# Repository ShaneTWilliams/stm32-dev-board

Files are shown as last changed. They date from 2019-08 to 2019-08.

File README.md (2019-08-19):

# stm32-dev-board
### ***A small-footprint, custom development PCB for the STM32 platform***

* This board's MCU is an STM32F072CBT6, meaning it is a higher-end 48-pin LQFP chip with 128kB of flash and an ARM Cortex-M0 core.

* The board supports CANbus, LINbus, I<sup>2</sup>C, SPI, USB,  and UART. Flashing can be achieved through an ST-LINK external flasher using the SWD protocol.

* The board is powered through a Micro-USB port and draws very little current. Power conversion occurs through a 5~3.3V linear regulator.

* The board has a 32.768kHz clock for RTC capabilities as well as an 8MHz system clock. It also features an indicator LED and a reset button.

* The footprint of the board is 19x52 mm and its 2.54 mm pitch headers allow it to be used with standard breadboards.

### Images ###






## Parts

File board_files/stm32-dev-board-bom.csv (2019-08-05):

Id | Designator | Package | Quantity | Designation | Supplier and ref
1 | C1,C4,C10 | C_0805_2012Metric_Pad1.15x1.40mm_HandSolder | 3 | 1u
2 | C2,C3,C8,C9 | C_0805_2012Metric_Pad1.15x1.40mm_HandSolder | 4 | 15p
3 | C5 | C_0805_2012Metric_Pad1.15x1.40mm_HandSolder | 1 | 10n
4 | C6,C7 | C_0805_2012Metric_Pad1.15x1.40mm_HandSolder | 2 | 4.7u
5 | C11,C12,C13,C14 | C_0805_2012Metric_Pad1.15x1.40mm_HandSolder | 4 | 100n
6 | D1 | LED_0805_2012Metric_Pad1.15x1.40mm_HandSolder | 1 | LED
7 | J1 | USB_Micro-B_Amphenol_10103594-0001LF_Horizontal | 1 | USB_B_Micro
8 | J2,J3 | PinHeader_1x20_P2.54mm_Vertical | 2 | Conn_01x20
9 | R1,R3,R4,R5,R6,R7 | R_0805_2012Metric_Pad1.15x1.40mm_HandSolder | 6 | 0
10 | R2 | R_0805_2012Metric_Pad1.15x1.40mm_HandSolder | 1 | 1k
11 | SW1 | PTS645SM43SMTR92_Switch | 1 | SW_Push
12 | U1 | SOT-223 | 1 | TC1262-33
13 | U2 | LQFP-48_7x7mm_P0.5mm | 1 | STM32F072CBT6
14 | Y1 | 2-SMD_Crystal | 1 | 8M
15 | Y2 | FC-135 | 1 | 32.768k

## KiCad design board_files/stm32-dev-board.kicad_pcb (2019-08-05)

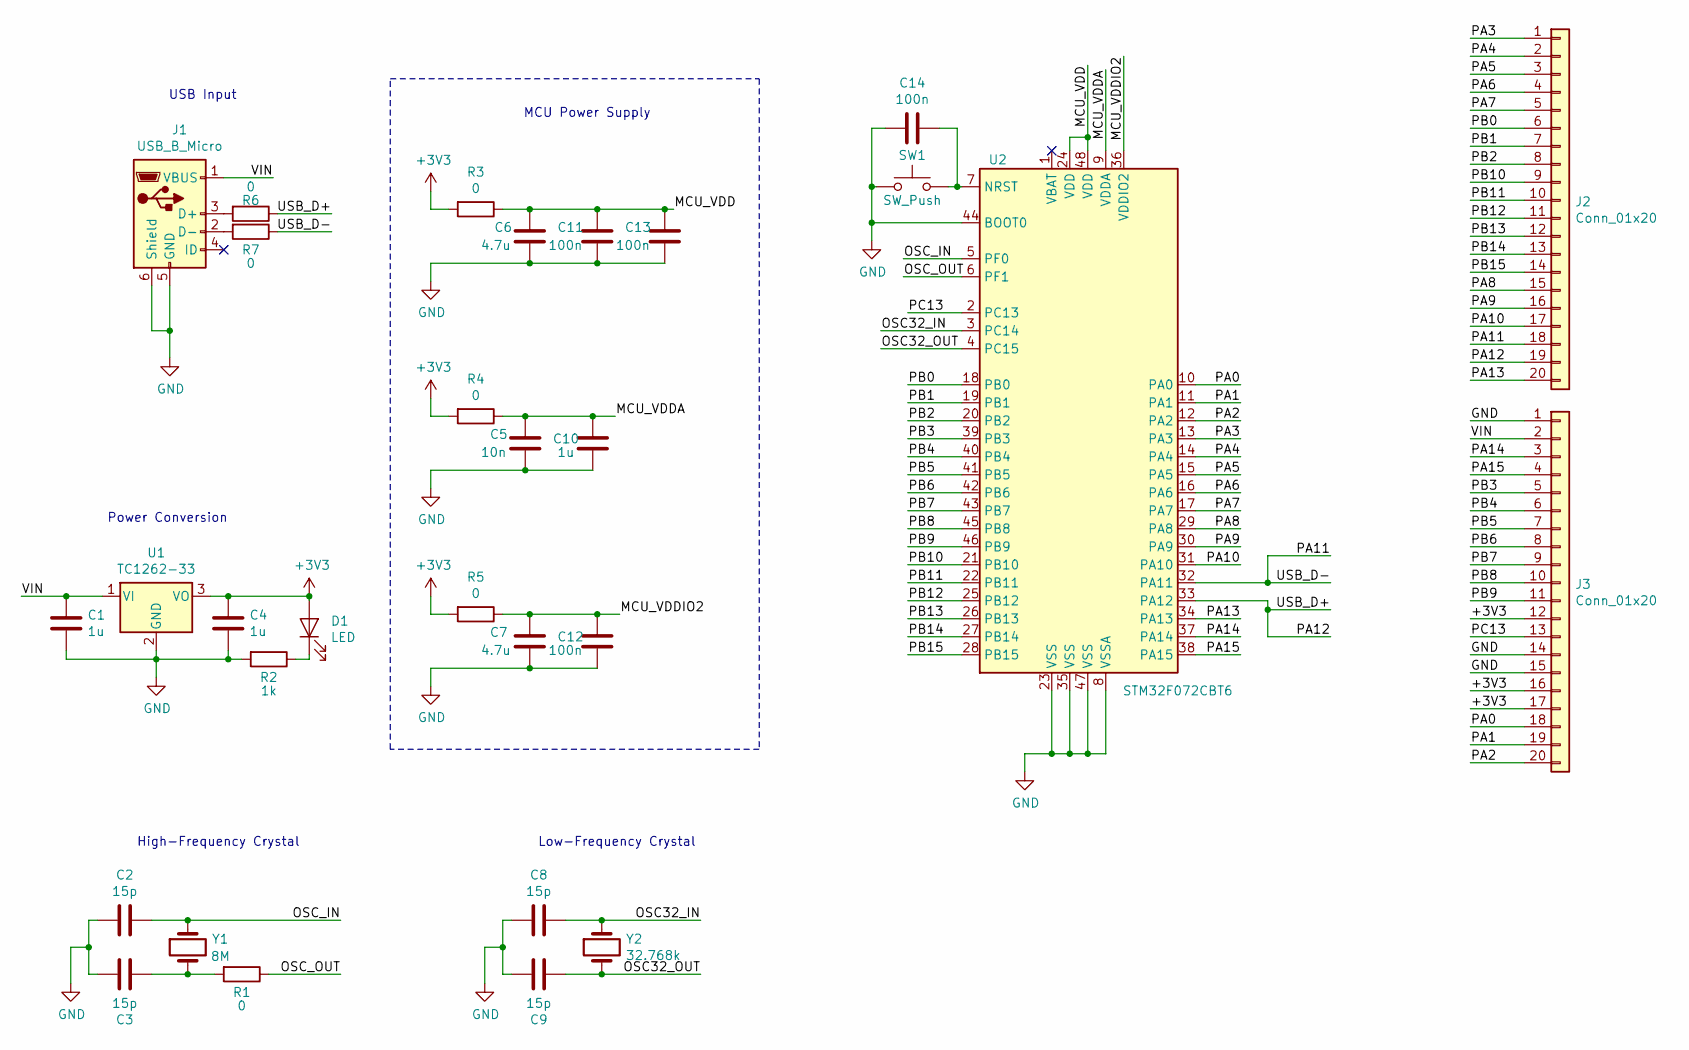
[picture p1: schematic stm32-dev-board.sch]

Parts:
C1, C4, C10: 1u; C_0805_2012Metric_Pad1.15x1.40mm_HandSolder
C2, C3, C8, C9: 15p; C_0805_2012Metric_Pad1.15x1.40mm_HandSolder
C5: 10n; C_0805_2012Metric_Pad1.15x1.40mm_HandSolder
C6, C7: 4.7u; C_0805_2012Metric_Pad1.15x1.40mm_HandSolder
C11, C12, C13, C14: 100n; C_0805_2012Metric_Pad1.15x1.40mm_HandSolder
D1: LED; LED_0805_2012Metric_Pad1.15x1.40mm_HandSolder
J1: USB_B_Micro; USB_Micro-B_Amphenol_10103594-0001LF_Horizontal
J2, J3: Conn_01x20; PinHeader_1x20_P2.54mm_Vertical
R1, R3, R4, R5, R6, R7: 0; R_0805_2012Metric_Pad1.15x1.40mm_HandSolder
R2: 1k; R_0805_2012Metric_Pad1.15x1.40mm_HandSolder
SW1: SW_Push; PTS645SM43SMTR92_Switch
U1: TC1262-33; SOT-223
U2: STM32F072CBT6; LQFP-48_7x7mm_P0.5mm
Y1: 8M; 2-SMD_Crystal
Y2: 32.768k; FC-135

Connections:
+3V3: C4.2, D1.2 (A), J3.12, J3.16, J3.17, R3.2, R4.2, R5.2, U1.3 (VO)
/MCU_VDD: C6.1, C11.1, C13.1, R3.1, U2.24 (VDD), U2.48 (VDD)
/MCU_VDDA: C5.1, C10.1, R4.1, U2.9 (VDDA)
/MCU_VDDIO2: C7.1, C12.1, R5.1, U2.36 (VDDIO2)
/OSC32_IN: C8.1, U2.3 (PC14), Y2.1
/OSC32_OUT: C9.2, U2.4 (PC15), Y2.2
/OSC_IN: C2.1, U2.5 (PF0), Y1.1
/OSC_OUT: R1.1, U2.6 (PF1)
/PA0: J3.18, U2.10 (PA0)
/PA1: J3.19, U2.11 (PA1)
/PA2: J3.20, U2.12 (PA2)
/PA3: J2.1, U2.13 (PA3)
/PA4: J2.2, U2.14 (PA4)
/PA5: J2.3, U2.15 (PA5)
/PA6: J2.4, U2.16 (PA6)
/PA7: J2.5, U2.17 (PA7)
/PA8: J2.15, U2.29 (PA8)
/PA9: J2.16, U2.30 (PA9)
/PA10: J2.17, U2.31 (PA10)
/PA11: J2.18, R7.1, U2.32 (PA11)
/PA12: J2.19, R6.1, U2.33 (PA12)
/PA13: J2.20, U2.34 (PA13)
/PA14: J3.3, U2.37 (PA14)
/PA15: J3.4, U2.38 (PA15)
/PB0: J2.6, U2.18 (PB0)
/PB1: J2.7, U2.19 (PB1)
/PB2: J2.8, U2.20 (PB2)
/PB3: J3.5, U2.39 (PB3)
/PB4: J3.6, U2.40 (PB4)
/PB5: J3.7, U2.41 (PB5)
/PB6: J3.8, U2.42 (PB6)
/PB7: J3.9, U2.43 (PB7)
/PB8: J3.10, U2.45 (PB8)
/PB9: J3.11, U2.46 (PB9)
/PB10: J2.9, U2.21 (PB10)
/PB11: J2.10, U2.22 (PB11)
/PB12: J2.11, U2.25 (PB12)
/PB13: J2.12, U2.26 (PB13)
/PB14: J2.13, U2.27 (PB14)
/PB15: J2.14, U2.28 (PB15)
/PC13: J3.13, U2.2 (PC13)
/VIN: C1.2, J1.1 (VBUS), J3.2, U1.1 (VI)
GND: C1.1, C2.2, C3.1, C4.1, C5.2, C6.2, C7.2, C8.2, C9.1, C10.2, C11.2, C12.2, C13.2, C14.2, J1.5 (GND), J1.6 (Shield), J3.1, J3.14, J3.15, R2.2, SW1.1, U1.2 (GND), U1.4, U2.8 (VSSA), U2.23 (VSS), U2.35 (VSS), U2.44 (BOOT0), U2.47 (VSS)
unnamed: C3.2, R1.2, Y1.2
unnamed: C14.1, SW1.2, U2.7 (NRST)
unnamed: D1.1 (K), R2.1
unnamed: J1.2 (D-), R7.2
unnamed: J1.3 (D+), R6.2

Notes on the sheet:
High-Frequency Crystal
Low-Frequency Crystal
USB Input
Power Conversion
MCU Power Supply

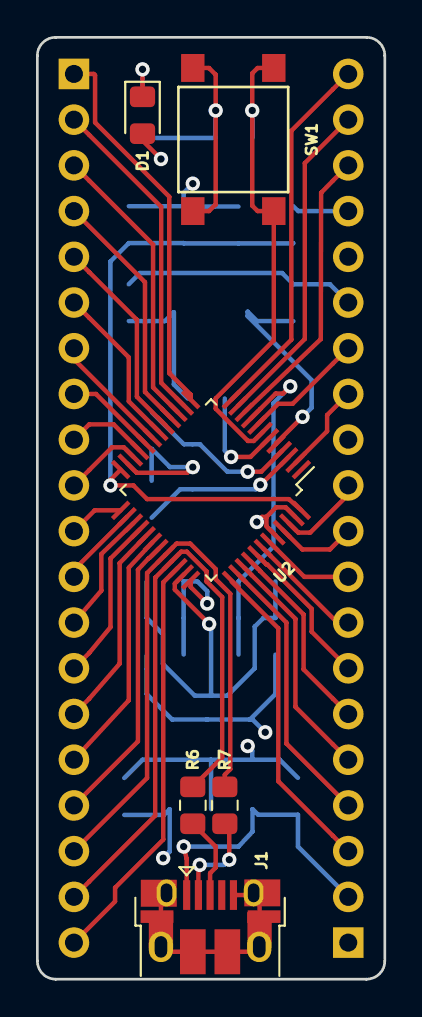
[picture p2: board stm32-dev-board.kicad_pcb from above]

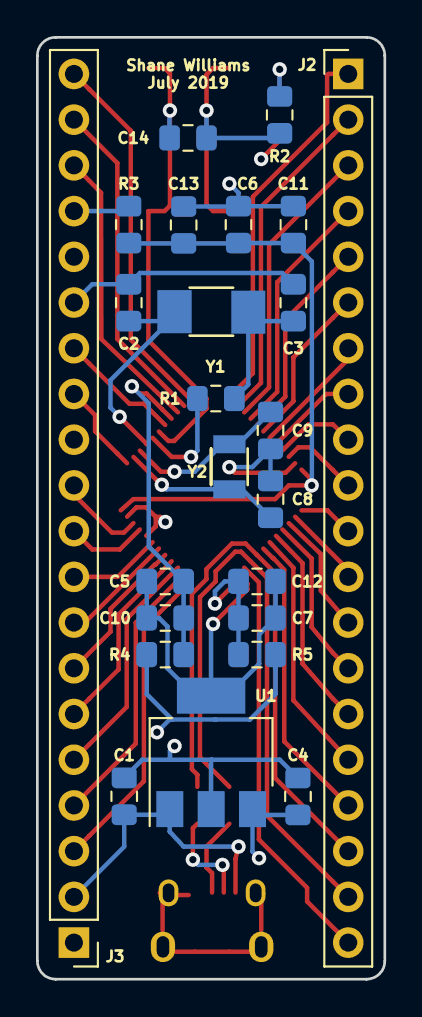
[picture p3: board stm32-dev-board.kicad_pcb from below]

Board: 4 copper layers, 19.3 x 52.3 mm, 30 parts (24 on the bottom side), 48 nets.

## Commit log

2019-08-05 Add board files
    [stm32-dev-board-bom.csv, stm32-dev-board.kicad_pcb, stm32-dev-board.sch]
2019-08-19 Add schematic metadata
    [stm32-dev-board.sch]
